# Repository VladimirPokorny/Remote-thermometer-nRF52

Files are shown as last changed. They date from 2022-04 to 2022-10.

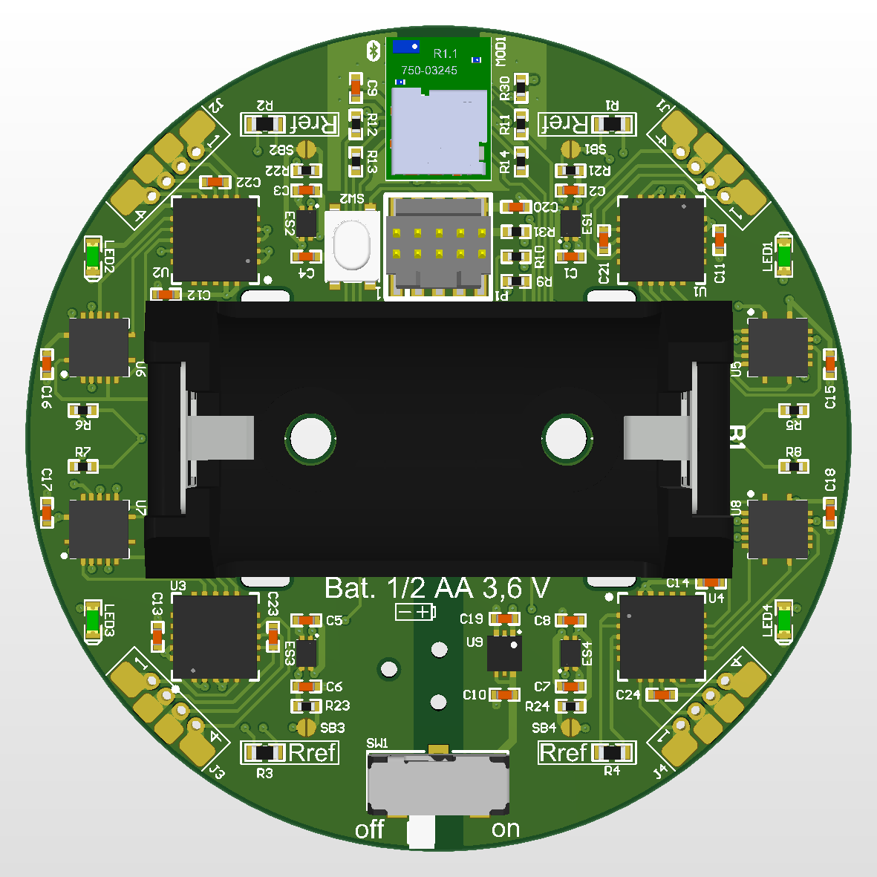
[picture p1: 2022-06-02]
Hardware Files/Schematic Layout PDF files/3D render/PCB_3D_TOP.png

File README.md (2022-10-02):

# Remote-thermometer-nRF52

The wireless thermometer project deals with a problem of direct temperature measurements in the rotor of an electric motor. The designated thermometr can measure temperature at up to four places in the motor rotor with average accuracy of 0.8 % from range +20 to +200°C. Main used chips are nRF52833 from Nordic Semiconductor and MAX31865 from Maxim integrated. Temperature is sensed by RTD sensors (PT100 or PT1000). 

The device is powered by small 1/2 AA battery and measured data is sent using the standardised Bluetooth Low Energy protocol so that the measuring system can be connected to a PC as well as to a laptop or smartphone with the appropriate client applications. No special receiver is not required. The system as a whole is characterised by high noise immunity, low power consumption, high accuracy and mechanical robustness, which has been measured up to a speed of 6500 RPM.

This project was devoleped as Master thesis project and the thesis is avaible [here](https://www.vut.cz/en/students/final-thesis/detail/142726).

Designed PCB:
PCB 3D Print

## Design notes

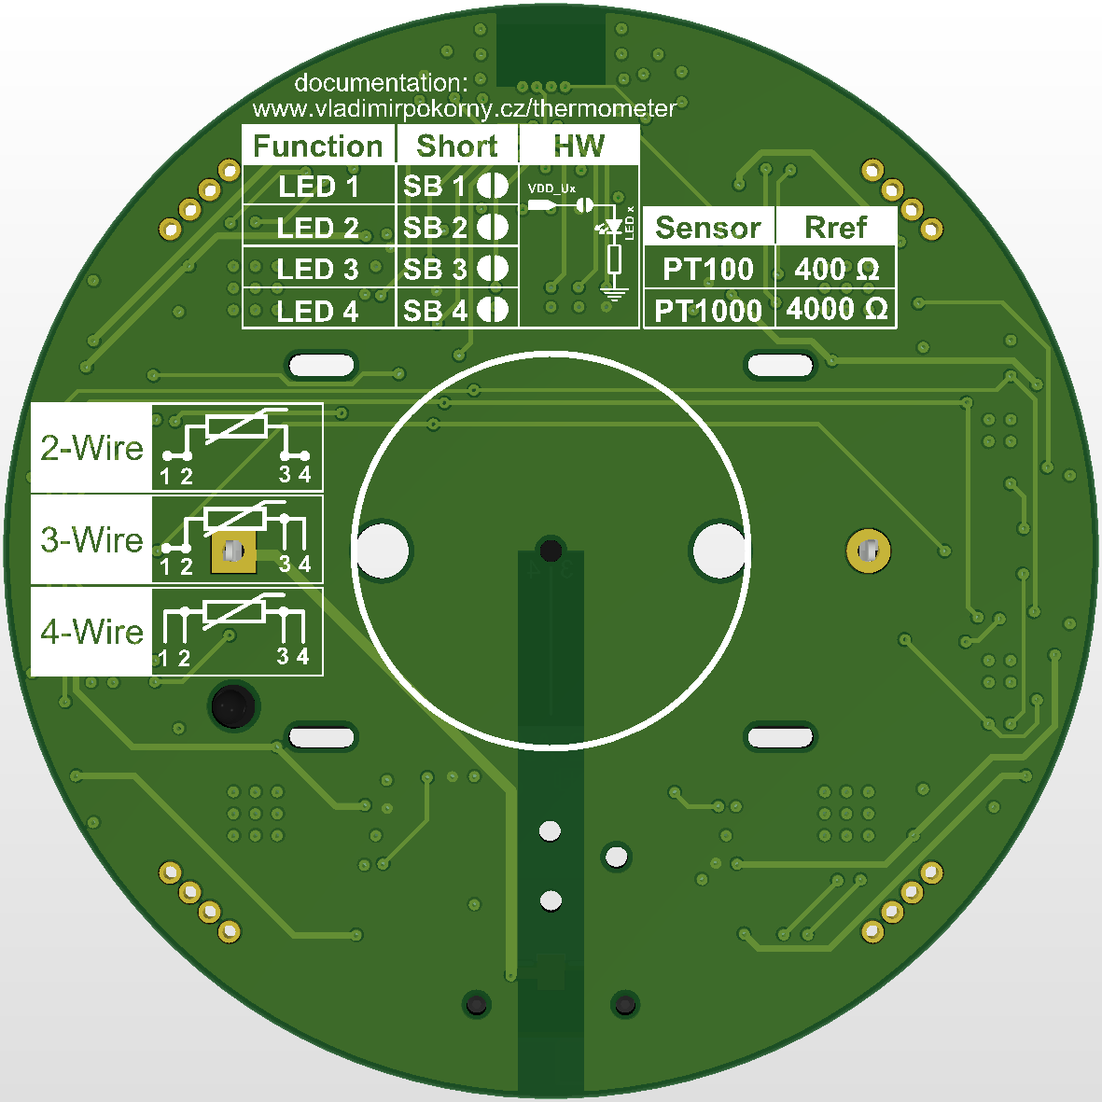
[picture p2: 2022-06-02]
Hardware Files/Schematic Layout PDF files/3D render/PCB_3D_Bottom.png

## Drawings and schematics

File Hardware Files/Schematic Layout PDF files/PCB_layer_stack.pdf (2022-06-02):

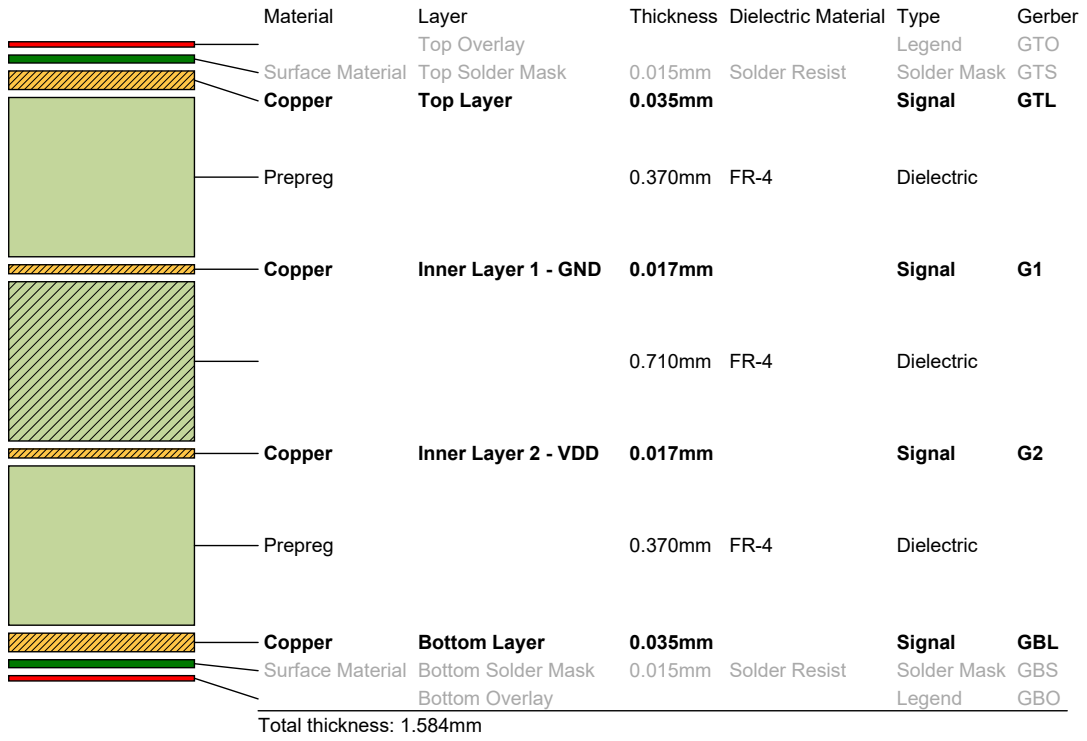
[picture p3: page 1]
Material; Layer; Thickness Dielectric Material Type; Gerber; Top Overlay; Legend; GTO; Surface Material Top Solder Mask; 0.015mm Solder Resist; Solder Mask GTS; Copper; Top Layer; Signal; GTL; Prepreg; Dielectric; Inner Layer 1 - GND 0.017mm; Inner Layer 2 - VDD 0.017mm; Bottom Layer; GBL; Surface Material Bottom Solder Mask; Solder Mask GBS; Bottom Overlay; GBO; Total thickness: 1.584mm

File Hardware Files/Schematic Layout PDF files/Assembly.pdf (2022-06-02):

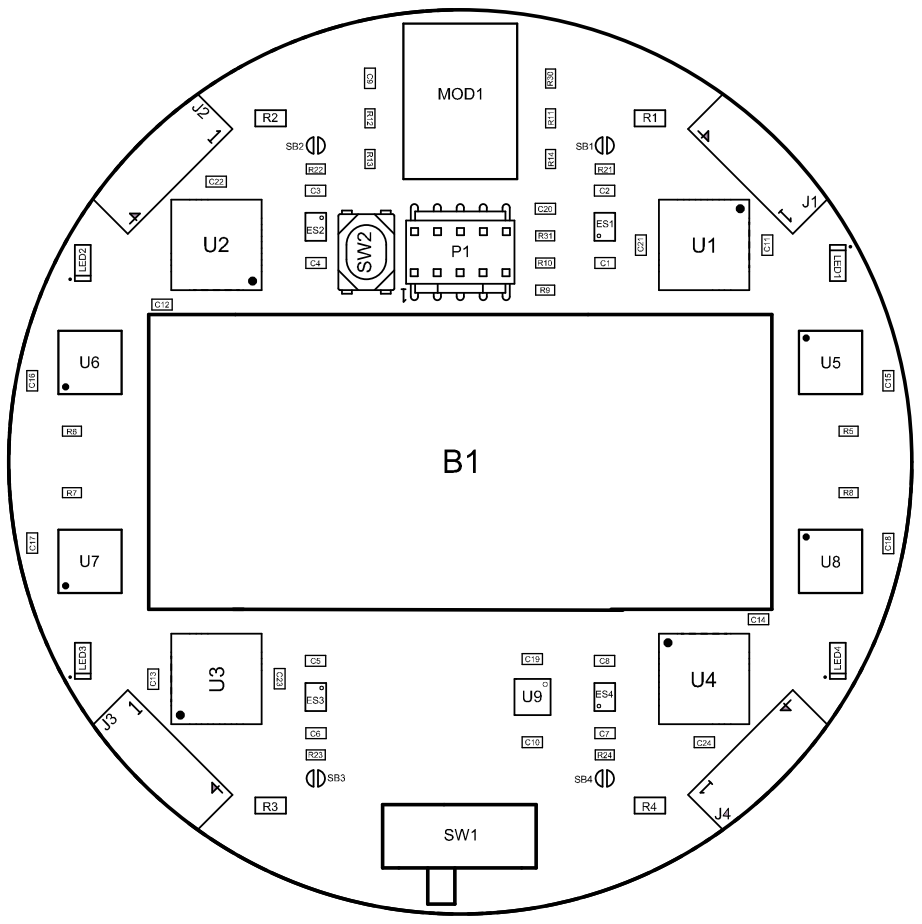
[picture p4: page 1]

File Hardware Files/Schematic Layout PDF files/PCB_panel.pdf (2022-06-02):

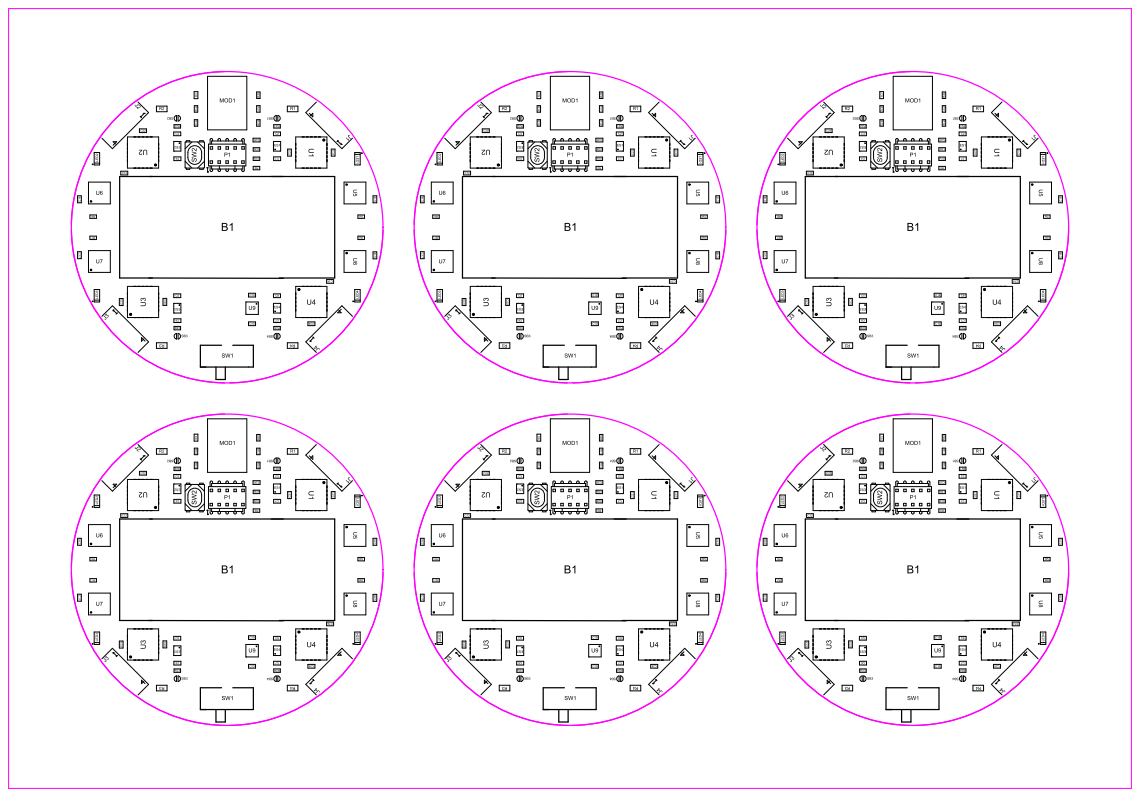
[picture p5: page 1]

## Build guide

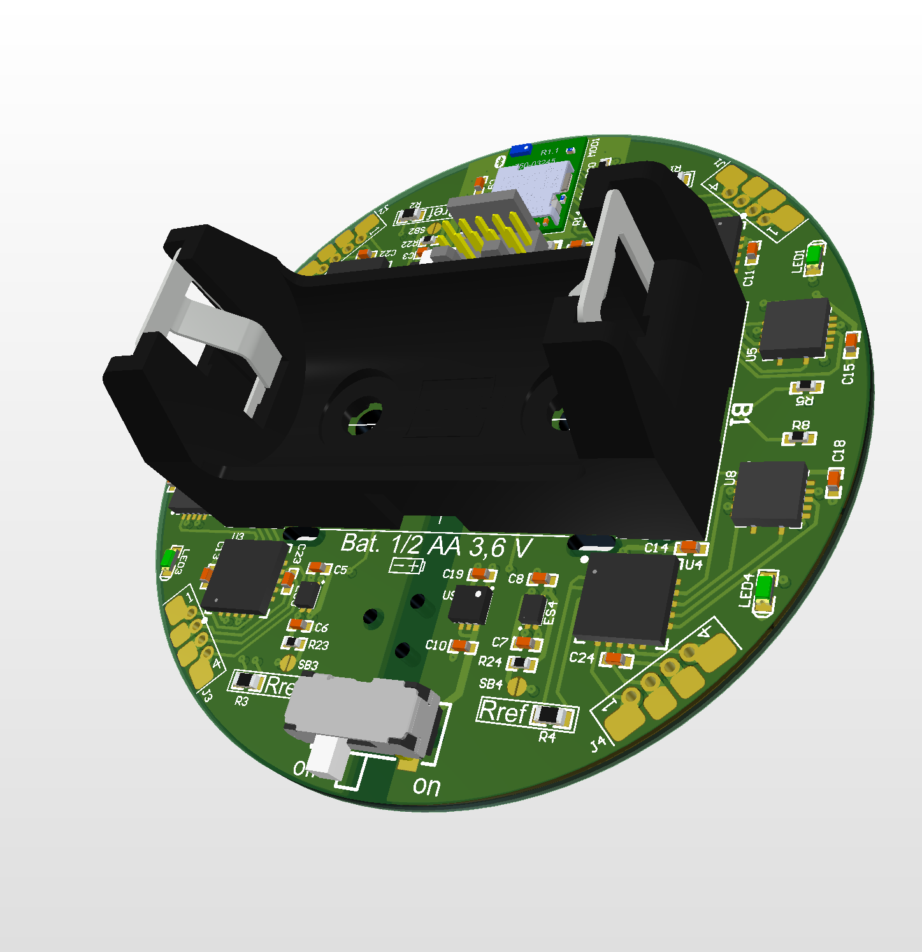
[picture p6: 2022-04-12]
PCB 3D Print.png

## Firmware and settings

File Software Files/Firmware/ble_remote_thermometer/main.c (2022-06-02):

/**
 * Copyright (c) Vladimir Pokorny
 *    email:  pokorny.v@email.cz
 *    web:    www.vladimirpokorny.cz

    https://www.vutbr.cz/studenti/zav-prace/detail/142726
 *    
 * Copyright (c) 2014 - 2021, Nordic Semiconductor ASA provided BLE template and tutorial
 * 
 ****************************************************************************************
 * This code was coded during a 3-months internship in Linz, Austria.
 * It contains a BLE application for reading temperatures from RTD sensors by MAX31865.
 * In the version 1.0 it reads temperatures from 4 sensors and sends them by BLE. Each Sensor
 * could be enabled or disabled. More about this work is written in the final Master thesis:
 * 
 * https://www.vut.cz/studenti/zav-prace/detail/142726
 * 
 * Service UUID:  0000272F5468616E6B734D6F6D446164
 *  UUID of Characteristics:
 *    Sensor 1: 000010005468616E6B734D6F6D446164
 *    Sensor 2: 000020005468616E6B734D6F6D446164
 *    Sensor 3: 000030005468616E6B734D6F6D446164
 *    Sensor 4: 000040005468616E6B734D6F6D446164
 */

/** @file
 *
 * @defgroup ble_remote_temperature_main main.c
 * @{
 * @ingroup ble_remote_temperature
 * @brief Project main file.
 *
 * This file contains a BLE app for reading temperatures from RTD sensors by MAX31865.
 * creating a new application. It has the code necessary to wakeup
 * from button, advertise, get a connection restart advertising on disconnect and if no new
 * connection created go back to system-off mode.
 */

#include <stdbool.h>
#include <stdint.h>
#include <string.h>

#include "MAX31865.h"
#include "our_service.h"

#include "nordic_common.h"
#include "nrf.h"
#include "app_error.h"
#include "ble.h"
#include "ble_hci.h"
#include "ble_srv_common.h"
#include "ble_advdata.h"
#include "ble_advertising.h"
#include "ble_conn_params.h"
#include "nrf_sdh.h"
#include "nrf_sdh_soc.h"
#include "nrf_sdh_ble.h"
#include "app_timer.h"
#include "fds.h"
#include "peer_manager.h"
#include "peer_manager_handler.h"
#include "bsp_btn_ble.h"
#include "sensorsim.h"
#include "ble_conn_state.h"
#include "nrf_ble_gatt.h"
#include "nrf_ble_qwr.h"
#include "nrf_pwr_mgmt.h"

#include "nrf_drv_spi.h"
#include "app_util_platform.h"
#include "nrf_gpio.h"
#include "nrf_delay.h"
#include "boards.h"
#include <string.h>
#include "math.h"

#include "nrf_log.h"
#include "nrf_log_ctrl.h"
#include "nrf_log_default_backends.h"

/***************************************************************************************************************/
/*  The characteristics of the RTD sensors, the reference resistors, reading interval and enabled sensors.     */
/*  Only this variables can be changed!                                                                        */
/*  More about this work, functions and variables is written in the final Master thesis:                       */
/*  https://www.vut.cz/studenti/zav-prace/detail/142726                                                        */
/***************************************************************************************************************/

#define RTD1_R0 (double)  100.0             // Resistance of the 1. RTD sensor, at 0 C
#define RTD2_R0 (double)  100.0             // Resistance of the 2. RTD sensor, at 0 C
#define RTD3_R0 (double)  100.0             // Resistance of the 3. RTD sensor, at 0 C
#define RTD4_R0 (double)  100.0             // Resistance of the 4. RTD sensor, at 0 C

#define RREF1 (double)    430.0             // Resistance of the reference resistor R1
#define RREF2 (double)    430.0             // Resistance of the reference resistor R2
#define RREF3 (double)    430.0             // Resistance of the reference resistor R3
#define RREF4 (double)    430.0             // Resistance of the reference resistor R4

#define READ_TEMPERATURE_INTERVAL   1000    // Read temperature interval in ms

#define SENSOR_1_ENABLE   true              // Enable or Disable sensor 1
#define SENSOR_2_ENABLE   true              // Enable or Disable sensor 2
#define SENSOR_3_ENABLE   false            // Enable or Disable sensor 3
#define SENSOR_4_ENABLE   false             // Enable or Disable sensor 4

// MAX31865_2WIRE   or    MAX31865_3WIRE    or    MAX31865_4WIRE
#define NUMWIRE_SENSOR_1  MAX31865_4WIRE    // Number of measuring wires sensor 1 
#define NUMWIRE_SENSOR_2  MAX31865_4WIRE    // Number of measuring wires sensor 2
#define NUMWIRE_SENSOR_3  MAX31865_4WIRE    // Number of measuring wires sensor 3
#define NUMWIRE_SENSOR_4  MAX31865_4WIRE    // Number of measuring wires sensor 4

/*----The characteristics of the RTD sensors, the reference resistors, reading interval and enabled sensors.---*/

#define DEVICE_NAME                     "Remote_Thermometer"                    /**< Name of device. Will be included in the advertising data. */
#define MANUFACTURER_NAME               "Vladimir_Pokorny"                      /**< Manufacturer. Will be passed to Device Information Service. */
#define APP_ADV_INTERVAL                160                                     /**< The advertising interval (in units of 0.625 ms. This value corresponds to 100 ms). */

#define APP_ADV_DURATION                6000                                    /**< The advertising duration (60 seconds) in units of 10 milliseconds. */
#define APP_BLE_OBSERVER_PRIO           3                                       /**< Application's BLE observer priority. You shouldn't need to modify this value. */
#define APP_BLE_CONN_CFG_TAG            1                                       /**< A tag identifying the SoftDevice BLE configuration. */

#define MIN_CONN_INTERVAL               MSEC_TO_UNITS(100, UNIT_1_25_MS)        /**< Minimum acceptable connection interval (0.1 seconds). */
#define MAX_CONN_INTERVAL               MSEC_TO_UNITS(200, UNIT_1_25_MS)        /**< Maximum acceptable connection interval (0.2 second). */
#define SLAVE_LATENCY                   0                                       /**< Slave latency. */
#define CONN_SUP_TIMEOUT                MSEC_TO_UNITS(4000, UNIT_10_MS)         /**< Connection supervisory timeout (4 seconds). */

#define FIRST_CONN_PARAMS_UPDATE_DELAY  APP_TIMER_TICKS(5000)                   /**< Time from initiating event (connect or start of notification) to first time sd_ble_gap_conn_param_update is called (5 seconds). */
#define NEXT_CONN_PARAMS_UPDATE_DELAY   APP_TIMER_TICKS(30000)                  /**< Time between each call to sd_ble_gap_conn_param_update after the first call (30 seconds). */
#define MAX_CONN_PARAMS_UPDATE_COUNT    3                                       /**< Number of attempts before giving up the connection parameter negotiation. */

#define SEC_PARAM_BOND                  1                                       /**< Perform bonding. */
#define SEC_PARAM_MITM                  0                                       /**< Man In The Middle protection not required. */
#define SEC_PARAM_LESC                  0                                       /**< LE Secure Connections not enabled. */
#define SEC_PARAM_KEYPRESS              0                                       /**< Keypress notifications not enabled. */
#define SEC_PARAM_IO_CAPABILITIES       BLE_GAP_IO_CAPS_NONE                    /**< No I/O capabilities. */
#define SEC_PARAM_OOB                   0                                       /**< Out Of Band data not available. */
#define SEC_PARAM_MIN_KEY_SIZE          7                                       /**< Minimum encryption key size. */
#define SEC_PARAM_MAX_KEY_SIZE          16                                      /**< Maximum encryption key size. */

#define DEAD_BEEF                       0xDEADBEEF                              /**< Value used as error code on stack dump, can be used to identify stack location on stack unwind. */

NRF_BLE_GATT_DEF(m_gatt);                                                       /**< GATT module instance. */
NRF_BLE_QWR_DEF(m_qwr);                                                         /**< Context for the Queued Write module.*/
BLE_ADVERTISING_DEF(m_advertising);                                             /**< Advertising module instance. */

static uint16_t m_conn_handle = BLE_CONN_HANDLE_INVALID;                        /**< Handle of the current connection. */

static volatile bool read_temperature_flag = false;                             /**< Flag for reading temperature. */


float     RTD_Temperature_1 = 0.0f;   // 1. sensor temperature (float)
float     RTD_Temperature_2 = 0.0f;   // 2. sensor temperature (float)
float     RTD_Temperature_3 = 0.0f;   // 3. sensor temperature (float)
float     RTD_Temperature_4 = 0.0f;   // 4. sensor temperature (float)

int32_t   int_temperature_1 = 0;      // 1. sensor temperature for transfering data over BLE
int32_t   int_temperature_2 = 0;      // 2. sensor temperature for transfering data over BLE
int32_t   int_temperature_3 = 0;      // 3. sensor temperature for transfering data over BLE
int32_t   int_temperature_4 = 0;      // 4. sensor temperature for transfering data over BLE

///**
// * @brief This structure contains various status information for our service. 
// * It only holds one entry now, but will be populated with more items as we go.
// * The name is based on the naming convention used in Nordic's SDKs. 
// * 'ble indicates that it is a Bluetooth Low Energy relevant structure and 
// * os is short for Our Service). 
// */

ble_os_t m_our_service;

// Declare an app_timer id variable and define our timer interval and define a timer interval
APP_TIMER_DEF(m_our_char_timer_id);
#define OUR_CHAR_TIMER_INTERVAL     APP_TIMER_TICKS(READ_TEMPERATURE_INTERVAL)

// Use UUIDs for service(s) used in your application.
static ble_uuid_t m_adv_uuids[] =                                               /**< Universally unique service identifiers. */
{
    {BLE_UUID_DEVICE_INFORMATION_SERVICE, BLE_UUID_TYPE_BLE}
};

static void advertising_start(bool erase_bonds);

/**@brief Callback function for asserts in the SoftDevice.
 *
 * @details This function will be called in case of an assert in the SoftDevice.
 *
 * @warning This handler is an example only and does not fit a final product. You need to analyze
 *          how your product is supposed to react in case of Assert.
 * @warning On assert from the SoftDevice, the system can only recover on reset.
 *
 * @param[in] line_num   Line number of the failing ASSERT call.
 * @param[in] file_name  File name of the failing ASSERT call.
 */
void assert_nrf_callback(uint16_t line_num, const uint8_t * p_file_name)
{
    app_error_handler(DEAD_BEEF, line_num, p_file_name);
}


// This is a timer event handler
static void timer_timeout_handler(void * p_context)
{
    read_temperature_flag = true;
    nrf_gpio_pin_toggle(LED_4);   // debugging on development kit
}
 

/**@brief Function for handling Peer Manager events.
 *
 * @param[in] p_evt  Peer Manager event.
 */
static void pm_evt_handler(pm_evt_t const * p_evt)
{
    pm_handler_on_pm_evt(p_evt);
    pm_handler_disconnect_on_sec_failure(p_evt);
    pm_handler_flash_clean(p_evt);

    switch (p_evt->evt_id)
    {
        case PM_EVT_PEERS_DELETE_SUCCEEDED:
            advertising_start(false);
            break;

        default:
            break;
    }
}


/**@brief Function for the Timer initialization.
 *
 * @details Initializes the timer module. This creates and starts application timers.
 */
static void timers_init(void)
{
    // Initialize timer module.
    ret_code_t err_code = app_timer_init();
    APP_ERROR_CHECK(err_code);

    // Create timers.
    // Initiate our timer
    app_timer_create(&m_our_char_timer_id, APP_TIMER_MODE_REPEATED, timer_timeout_handler);
}


/**@brief Function for the GAP initialization.
 *
 * @details This function sets up all the necessary GAP (Generic Access Profile) parameters of the
 *          device including the device name, appearance, and the preferred connection parameters.
 */
static void gap_params_init(void)
{
    ret_code_t              err_code;
    ble_gap_conn_params_t   gap_conn_params;
    ble_gap_conn_sec_mode_t sec_mode;

    BLE_GAP_CONN_SEC_MODE_SET_OPEN(&sec_mode);

    err_code = sd_ble_gap_device_name_set(&sec_mode,
                                          (const uint8_t *)DEVICE_NAME,
                                          strlen(DEVICE_NAME));
    APP_ERROR_CHECK(err_code);

    memset(&gap_conn_params, 0, sizeof(gap_conn_params));

    gap_conn_params.min_conn_interval = MIN_CONN_INTERVAL;
    gap_conn_params.max_conn_interval = MAX_CONN_INTERVAL;
    gap_conn_params.slave_latency     = SLAVE_LATENCY;
    gap_conn_params.conn_sup_timeout  = CONN_SUP_TIMEOUT;

    err_code = sd_ble_gap_ppcp_set(&gap_conn_params);
    APP_ERROR_CHECK(err_code);
}


/**@brief Function for initializing the GATT module.
 */
static void gatt_init(void)
{
    ret_code_t err_code = nrf_ble_gatt_init(&m_gatt, NULL);
    APP_ERROR_CHECK(err_code);
}


/**@brief Function for handling Queued Write Module errors.
 *
 * @details A pointer to this function will be passed to each service which may need to inform the
 *          application about an error.
 *
 * @param[in]   nrf_error   Error code containing information about what went wrong.
 */
static void nrf_qwr_error_handler(uint32_t nrf_error)
{
    APP_ERROR_HANDLER(nrf_error);
}


/**@brief Function for initializing services that will be used by the application.
 */
static void services_init(void)
{
    ret_code_t         err_code;
    nrf_ble_qwr_init_t qwr_init = {0};

    // Initialize Queued Write Module.
    qwr_init.error_handler = nrf_qwr_error_handler;

    err_code = nrf_ble_qwr_init(&m_qwr, &qwr_init);
    APP_ERROR_CHECK(err_code);

    our_service_init(&m_our_service);
}


/**@brief Function for handling the Connection Parameters Module.
 *
 * @details This function will be called for all events in the Connection Parameters Module which
 *          are passed to the application.
 *          @note All this function does is to disconnect. This could have been done by simply
 *                setting the disconnect_on_fail config parameter, but instead we use the event
 *                handler mechanism to demonstrate its use.
 *
 * @param[in] p_evt  Event received from the Connection Parameters Module.
 */
static void on_conn_params_evt(ble_conn_params_evt_t * p_evt)
{
    ret_code_t err_code;

    if (p_evt->evt_type == BLE_CONN_PARAMS_EVT_FAILED)
    {
        err_code = sd_ble_gap_disconnect(m_conn_handle, BLE_HCI_CONN_INTERVAL_UNACCEPTABLE);
        APP_ERROR_CHECK(err_code);
    }
}


/**@brief Function for handling a Connection Parameters error.
 *
 * @param[in] nrf_error  Error code containing information about what went wrong.
 */
static void conn_params_error_handler(uint32_t nrf_error)
{
    APP_ERROR_HANDLER(nrf_error);
}


/**@brief Function for initializing the Connection Parameters module.
 */
static void conn_params_init(void)
{
    ret_code_t             err_code;
    ble_conn_params_init_t cp_init;

    memset(&cp_init, 0, sizeof(cp_init));

    cp_init.p_conn_params                  = NULL;
    cp_init.first_conn_params_update_delay = FIRST_CONN_PARAMS_UPDATE_DELAY;
    cp_init.next_conn_params_update_delay  = NEXT_CONN_PARAMS_UPDATE_DELAY;
    cp_init.max_conn_params_update_count   = MAX_CONN_PARAMS_UPDATE_COUNT;
    cp_init.start_on_notify_cccd_handle    = BLE_GATT_HANDLE_INVALID;
    cp_init.disconnect_on_fail             = false;
    cp_init.evt_handler                    = on_conn_params_evt;
    cp_init.error_handler                  = conn_params_error_handler;

    err_code = ble_conn_params_init(&cp_init);
    APP_ERROR_CHECK(err_code);
}


/**@brief Function for starting timers.
 */
static void application_timers_start(void)
{
    // Start our timer
    app_timer_start(m_our_char_timer_id, OUR_CHAR_TIMER_INTERVAL, NULL);
}


/**@brief Function for putting the chip into sleep mode.
 *
 * @note This function will not return.
 */
static void sleep_mode_enter(void)
{
    ret_code_t err_code;

    err_code = bsp_indication_set(BSP_INDICATE_IDLE);
    APP_ERROR_CHECK(err_code);

    // Prepare wakeup buttons.
    err_code = bsp_btn_ble_sleep_mode_prepare();
    APP_ERROR_CHECK(err_code);

    // Go to system-off mode (this function will not return; wakeup will cause a reset).
    err_code = sd_power_system_off();
    APP_ERROR_CHECK(err_code);
}


/**@brief Function for handling advertising events.
 *
 * @details This function will be called for advertising events which are passed to the application.
 *
 * @param[in] ble_adv_evt  Advertising event.
 */
static void on_adv_evt(ble_adv_evt_t ble_adv_evt)
{
    ret_code_t err_code;

    switch (ble_adv_evt)
    {
        case BLE_ADV_EVT_FAST:
            NRF_LOG_INFO("Fast advertising.");
            err_code = bsp_indication_set(BSP_INDICATE_ADVERTISING);
            APP_ERROR_CHECK(err_code);
            break;

        case BLE_ADV_EVT_IDLE:
            sleep_mode_enter();
            break;

        default:
            break;
    }
}
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
int main(void)
{
    bool erase_bonds;

    log_init();
    timers_init();
    buttons_leds_init(&erase_bonds);

    // Initialization of slave selects pins
    nrf_gpio_cfg_output(SLAVE_1);
    nrf_gpio_cfg_output(SLAVE_2);
    nrf_gpio_cfg_output(SLAVE_3);
    nrf_gpio_cfg_output(SLAVE_4);

    // Initialization of enable pins for load switches
    nrf_gpio_cfg_output(EN_1);
    nrf_gpio_cfg_output(EN_2);
    nrf_gpio_cfg_output(EN_3);
    nrf_gpio_cfg_output(EN_4);

    // Initialization of board LEDs (only on development kit)
    bsp_board_init(BSP_INIT_LEDS);          
    
    // Initialization of SPI
    spi_init();                             
    
    // Initialization of MAX31865
    MAX31865_init(NUMWIRE_SENSOR_1, SLAVE_1);         
    MAX31865_init(NUMWIRE_SENSOR_2, SLAVE_2);       
    MAX31865_init(NUMWIRE_SENSOR_3, SLAVE_3);
    MAX31865_init(NUMWIRE_SENSOR_4, SLAVE_4);

    power_management_init();
    ble_stack_init();
    gap_params_init();
    gatt_init();
    advertising_init();
    services_init();
    conn_params_init();
    peer_manager_init();

    // Start execution.
    NRF_LOG_INFO("Measuring temperature started.");
    application_timers_start();

    advertising_start(erase_bonds);

    // Enter main loop.
    for (;;)
    {
      idle_state_handle();    // entering power save mode

      if (read_temperature_flag == true)
      {
        if (SENSOR_1_ENABLE == true)
        {
          // 1. Temperature sensor
          nrf_gpio_pin_set(EN_1);
          nrf_delay_ms(2);

          //MAX31865_init(MAX31865_4WIRE, SLAVE_1);
          RTD_Temperature_1 = readTemperature(RTD1_R0, RREF1, SLAVE_1);
          int_temperature_1 = RTD_Temperature_1 * 1000;

          nrf_gpio_pin_clear(EN_1);

          our_temperature_characteristic_update_1(&m_our_service, &int_temperature_1);        
        }

        if (SENSOR_2_ENABLE == true)
        {
          // 2. Temperature sensor
          nrf_gpio_pin_set(EN_2);
          nrf_delay_ms(2);

          //MAX31865_init(MAX31865_4WIRE, SLAVE_2);
          RTD_Temperature_2 = readTemperature(RTD2_R0, RREF2, SLAVE_2);
          int_temperature_2 = RTD_Temperature_2 * 1000;

          nrf_gpio_pin_clear(EN_2);

          our_temperature_characteristic_update_2(&m_our_service, &int_temperature_2);
        }

        if (SENSOR_3_ENABLE == true)
        {
          // 3. Temperature sensor
          nrf_gpio_pin_set(EN_3);
          nrf_delay_ms(2);
          
          //MAX31865_init(MAX31865_4WIRE, SLAVE_3);
          RTD_Temperature_3 = readTemperature(RTD3_R0, RREF3, SLAVE_3);
          int_temperature_3 = RTD_Temperature_3 * 1000;

          nrf_gpio_pin_clear(EN_3);

          our_temperature_characteristic_update_3(&m_our_service, &int_temperature_3);
        }

        if (SENSOR_3_ENABLE == true)
        {
          // 4. Temperature sensor
          nrf_gpio_pin_set(EN_4);
          nrf_delay_ms(2);

          //MAX31865_init(MAX31865_4WIRE, SLAVE_4);
          RTD_Temperature_4 = readTemperature(RTD4_R0, RREF4, SLAVE_4);
          int_temperature_4 = RTD_Temperature_4 * 1000;

          nrf_gpio_pin_clear(EN_4);

          our_temperature_characteristic_update_4(&m_our_service, &int_temperature_4);
        }       
        
        read_temperature_flag = false;

      }
    }
}

/**
 * @}
 */

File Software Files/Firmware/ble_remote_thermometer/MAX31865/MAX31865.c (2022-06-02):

#include "MAX31865.h"

#include <stdio.h>
#include <stdbool.h>
#include <stdlib.h>

#include "stdint.h"

#include "nrf_drv_spi.h"
#include "app_util_platform.h"
#include "nrf_gpio.h"
#include "nrf_delay.h"
#include "boards.h"
//#include "app_error.h"
#include <string.h>
#include "nrf_log.h"
#include "nrf_log_ctrl.h"
#include "nrf_log_default_backends.h"
#include "math.h"



#define SPI_INSTANCE  0 /**< SPI instance index. */
static const nrf_drv_spi_t spi = NRF_DRV_SPI_INSTANCE(SPI_INSTANCE);  /**< SPI instance. */
static volatile bool spi_xfer_done;  /**< Flag used to indicate that SPI instance completed the transfer. */


/**
 * @brief SPI user event handler.
 * @param event
 */
void spi_event_handler(nrf_drv_spi_evt_t const * p_event,
                       void *                    p_context)           // From SPI example
{
    spi_xfer_done = true;
}

void spi_init(void)
{
    nrf_drv_spi_config_t spi_config = NRF_DRV_SPI_DEFAULT_CONFIG;

    spi_config.ss_pin     = NRF_SPI_PIN_NOT_CONNECTED;  // 31   P0.31   (CS on MAX31865)
    spi_config.miso_pin   = SPI_MISO_PIN;               // 30   P0.30   (SDO on MAX)
    spi_config.mosi_pin   = SPI_MOSI_PIN;               // 29   P0.29   (SDI on MAX)
    spi_config.sck_pin    = SPI_SCK_PIN;                // 26   P0.26   (CLK on MAX)

    spi_config.mode       = NRF_DRV_SPI_MODE_1;         // set up from datasheet (it is able to use spi mode 1 or 3)
    spi_config.frequency  = NRF_DRV_SPI_FREQ_4M;        // max frequency is 5 MHz
    spi_config.bit_order  = NRF_DRV_SPI_BIT_ORDER_MSB_FIRST;
    
    APP_ERROR_CHECK(nrf_drv_spi_init(&spi, &spi_config, spi_event_handler, NULL));
}


/**************************************************************************/
/*!
    @brief Initialize the SPI interface and set the number of RTD wires used
    @param wires The number of wires in enum format. Can be MAX31865_2WIRE,
    MAX31865_3WIRE, or MAX31865_4WIRE
    @return True
*/
/**************************************************************************/
bool MAX31865_init(max31865_numwires_t wires,
           slave_selects_t slave_select)
{
    setWires(wires, slave_select);
    enableBias(false, slave_select);
    autoConvert(false, slave_select);
    clearFault(slave_select);

    NRF_LOG_INFO("Initialization of MAX31865 was succesful");
    return true;
}


/**************************************************************************/
/*!
    @brief How many wires we have in our RTD setup, can be MAX31865_2WIRE,
    MAX31865_3WIRE, or MAX31865_4WIRE
    @param wires The number of wires in enum format
*/
/**************************************************************************/
void setWires(max31865_numwires_t wires,
              slave_selects_t slave_select) 
{
     uint8_t t = readRegister8(MAX31865_CONFIG_REG, slave_select);
     if (wires == MAX31865_3WIRE)
     {
        t |= MAX31865_CONFIG_3WIRE;
     }

     else 
     {
        // 2 or 4 wire
        t &= ~MAX31865_CONFIG_3WIRE;
     }

     writeRegister8(MAX31865_CONFIG_REG, t, slave_select);
}


/**************************************************************************/
/*!
    @brief Enable the bias voltage on the RTD sensor
    @param b If true bias is enabled, else disabled
*/
/**************************************************************************/
void enableBias(bool b,
                slave_selects_t slave_select) 
{
  uint8_t t = readRegister8(MAX31865_CONFIG_REG, slave_select);
  if (b) {
    t |= MAX31865_CONFIG_BIAS; // enable bias
  } else {
    t &= ~MAX31865_CONFIG_BIAS; // disable bias
  }
  writeRegister8(MAX31865_CONFIG_REG, t, slave_select);
}


/**************************************************************************/
/*!
    @brief Whether we want to have continuous conversions (50/60 Hz)
    @param b If true, auto conversion is enabled
*/
/**************************************************************************/
void autoConvert( bool b,
                  slave_selects_t slave_select) 
{
    uint8_t t = readRegister8(MAX31865_CONFIG_REG, slave_select);
    if (b) {
      t |= MAX31865_CONFIG_MODEAUTO; // enable autoconvert
    } else {
      t &= ~MAX31865_CONFIG_MODEAUTO; // disable autoconvert
    }
    writeRegister8(MAX31865_CONFIG_REG, t, slave_select);
}


/**************************************************************************/
/*!
    @brief Clear all faults in FAULTSTAT
*/
/**************************************************************************/
void clearFault(slave_selects_t slave_select) 
{
    uint8_t t = readRegister8(MAX31865_CONFIG_REG, slave_select);
    t &= ~0x2C;
    t |= MAX31865_CONFIG_FAULTSTAT;
    writeRegister8(MAX31865_CONFIG_REG, t, slave_select);
}


/**************************************************************************/
/*!
    @brief Read the raw 8-bit FAULTSTAT register
    @return The raw unsigned 8-bit FAULT status register
*/
/**************************************************************************/
uint8_t readFault(slave_selects_t slave_select) 
{
    return readRegister8(MAX31865_FAULTSTAT_REG, slave_select);
}


/**************************************************************************/
/*!
    @brief Whether we want filter out 50Hz noise or 60Hz noise
    @param b If true, 50Hz noise is filtered, else 60Hz(default)
*/
/**************************************************************************/
void enable50Hz(bool b,
                slave_selects_t slave_select) 
{
    uint8_t t = readRegister8(MAX31865_CONFIG_REG, slave_select);
    if (b) {
      t |= MAX31865_CONFIG_FILT50HZ;
    } else {
      t &= ~MAX31865_CONFIG_FILT50HZ;
    }
    writeRegister8(MAX31865_CONFIG_REG, t, slave_select);
}
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

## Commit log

2022-03-07 working temperature measurement
2022-06-02 Master's Thesis release
    [Copy of Gerber Files.GBL, Copy of Gerber Files.GBO, Copy of Gerber Files.GBP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]
